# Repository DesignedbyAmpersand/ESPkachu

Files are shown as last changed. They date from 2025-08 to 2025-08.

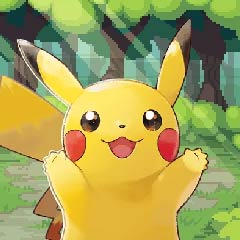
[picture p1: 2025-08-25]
wallpaper.jpg

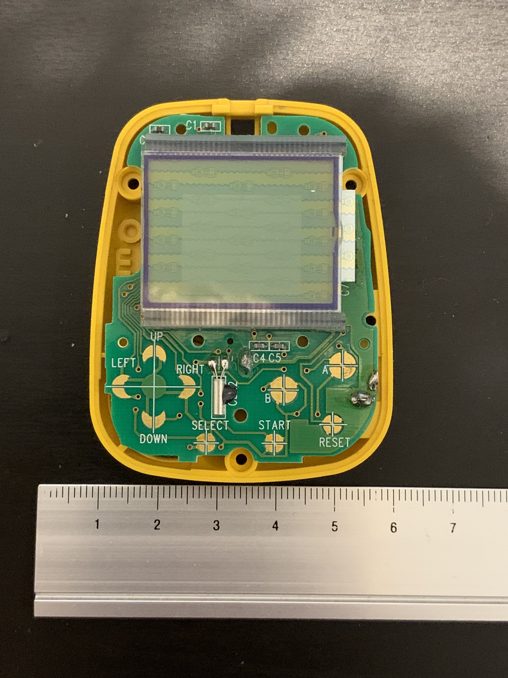
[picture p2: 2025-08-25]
IMG_2900.jpg

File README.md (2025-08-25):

https://www.reddit.com/r/SBCGaming/comments/13wpaec/this_is_espkachu

It’s an ESP32 inside a broken Pocket Pikachu. It uses Nathalis’s NCAT software to play NES, GBC, and SMS on a 1.3” IPS screen. There’s a 100mAh battery crammed in there that lasts 16 minutes, and it’s recharged via a tiny external PCB because I didn’t want to cut a massive hole for a USB C socket. The SD card can be accessed by unscrewing the battery cover. It uses all but 1 of the original screws with a bunch of the inside carved away to make space.

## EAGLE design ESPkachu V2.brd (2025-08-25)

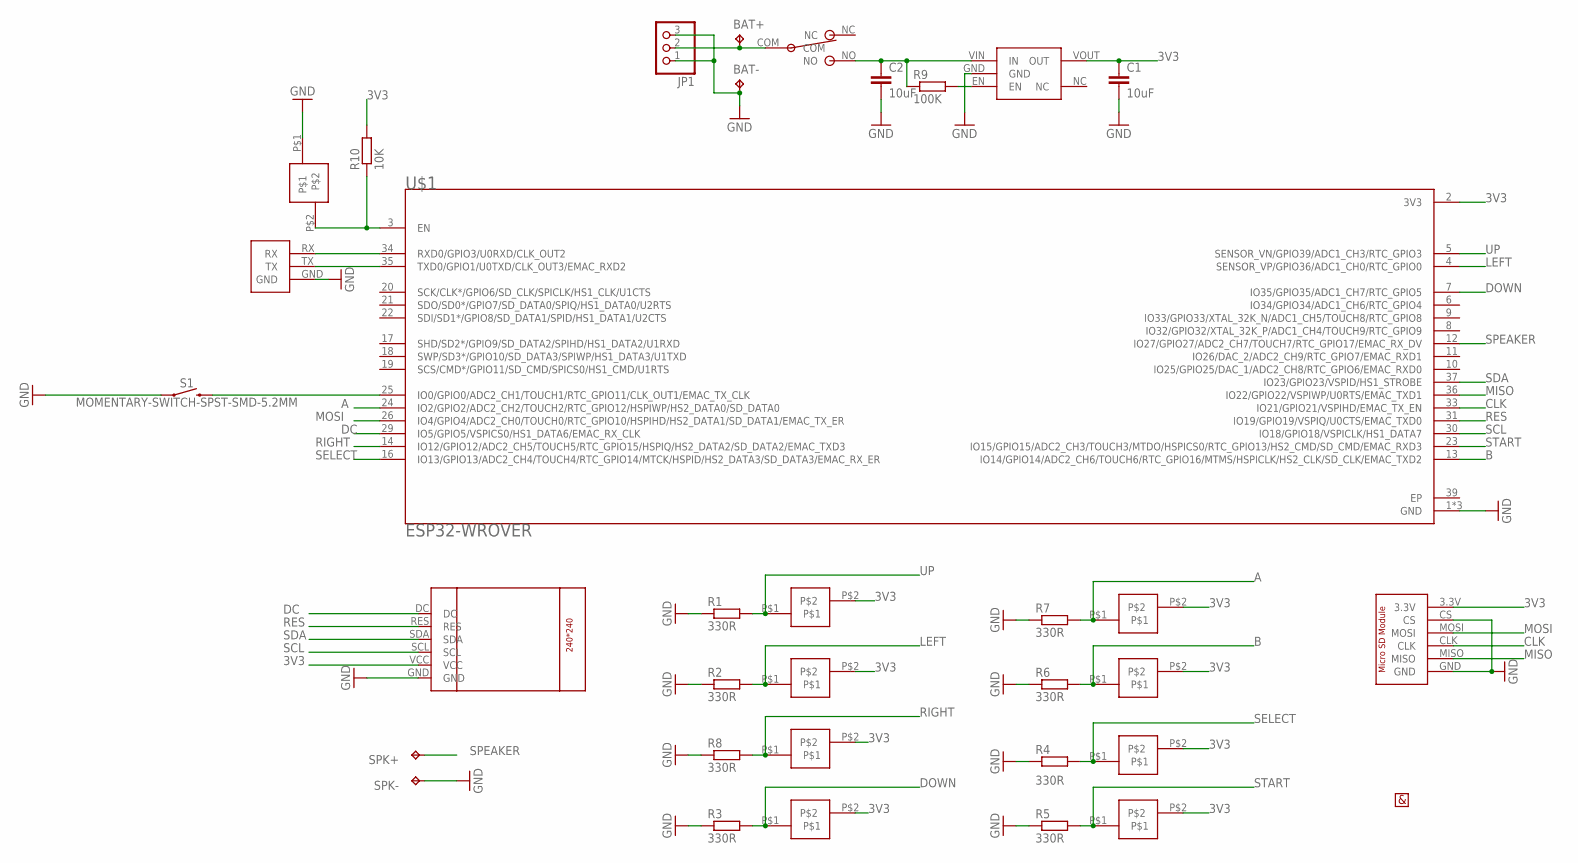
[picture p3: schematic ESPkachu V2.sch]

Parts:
A: ESPKACHU-PAD
B: ESPKACHU-PAD
BAT+: TPTP20R; TP20R
BAT-: TPTP20R; TP20R
C1, C2: 10uF; C0805
DOWN: ESPKACHU-PAD
JP1: PINHD-1X03_2.54-S; 1X03-S
LEFT: ESPKACHU-PAD
R1, R2, R3, R4, R5, R6, R7, R8: 330R; M0805
R9: 100K; M0805
R10: 10K; M0805
RESET: ESPKACHU-PAD
RIGHT: ESPKACHU-PAD
S1: MOMENTARY-SWITCH-SPST-SMD-5.2MM; TACTILE_SWITCH_SMD_5.2MM
SELECT: ESPKACHU-PAD
SPK+: TPTP20R; TP20R
SPK-: TPTP20R; TP20R
START: ESPKACHU-PAD
U$1: ESP32-WROVER; XCVR-ESP32-WROVER
U$2: LCD-ST7789-1.3INCH
U$3: ESPRESSO-MICROSD-MODULE
U$4: SS12D00-SWITCH
U$5: AMP-HALF
U$6: AP2112-REGULATOR; SOT25
U$7: ESPKACHU-UART
UP: ESPKACHU-PAD

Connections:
3V3: A.P$2, B.P$2, C1.1, DOWN.P$2, LEFT.P$2, R10.2, RIGHT.P$2, SELECT.P$2, START.P$2, U$1.2 (3V3), U$2.VCC, U$3.3.3V, U$6.VOUT (OUT), UP.P$2
A: A.P$1, R7.2, U$1.24 (IO2/GPIO2/ADC2_CH2/TOUCH2/RTC_GPIO12/HS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)
B: B.P$1, R6.2, U$1.13 (IO14/GPIO14/ADC2_CH6/TOUCH6/RTC_GPIO16/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)
CLK: U$1.33 (IO21/GPIO21/VSPIHD/EMAC_TX_EN), U$3.CLK
DC: U$1.29 (IO5/GPIO5/VSPICS0/HS1_DATA6/EMAC_RX_CLK), U$2.DC
DOWN: DOWN.P$1, R3.2, U$1.7 (IO35/GPIO35/ADC1_CH7/RTC_GPIO5)
EP: U$1.39 (EP)
GND: BAT-.TP, C1.2, C2.2, JP1.1, JP1.3, R1.1, R2.1, R3.1, R4.1, R5.1, R6.1, R7.1, R8.1, RESET.P$1, S1.1, S1.2 (1), SPK-.TP, U$1.1 (GND), U$1.15 (GND), U$1.38 (GND), U$2.GND, U$3.CS, U$3.GND, U$6.GND, U$7.GND
LEFT: LEFT.P$1, R2.2, U$1.4 (SENSOR_VP/GPIO36/ADC1_CH0/RTC_GPIO0)
MISO: U$1.36 (IO22/GPIO22/VSPIWP/U0RTS/EMAC_TXD1), U$3.MISO
MOSI: U$1.26 (IO4/GPIO4/ADC2_CH0/TOUCH0/RTC_GPIO10/HS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), U$3.MOSI
unnamed: R9.2, U$6.EN
unnamed: C2.1, R9.1, U$4.NO, U$6.VIN (IN)
unnamed: R10.1, RESET.P$2, U$1.3 (EN)
unnamed: S1.3 (2), S1.4 (2), U$1.25 (IO0/GPIO0/ADC2_CH1/TOUCH1/RTC_GPIO11/CL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)
unnamed: U$1.34 (RXD0/GPIO3/U0RXD/CLK_OUT2), U$7.RX
unnamed: U$1.35 (TXD0/GPIO1/U0TXD/CLK_OUT3/EMAC_RXD2), U$7.TX
unnamed: BAT+.TP, JP1.2, U$4.COM
RES: U$1.31 (IO19/GPIO19/VSPIQ/U0CTS/EMAC_TXD0), U$2.RES
RIGHT: R8.2, RIGHT.P$1, U$1.14 (IO12/GPIO12/ADC2_CH5/TOUCH5/RTC_GPIO15/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)
SCL: U$1.30 (IO18/GPIO18/VSPICLK/HS1_DATA7), U$2.SCL
SDA: U$1.37 (IO23/GPIO23/VSPID/HS1_STROBE), U$2.SDA
SELECT: R4.2, SELECT.P$1, U$1.16 (IO13/GPIO13/ADC2_CH4/TOUCH4/RTC_GPIO14/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)
SPEAKER: SPK+.TP, U$1.12 (IO27/GPIO27/ADC2_CH7/TOUCH7/RTC_GPIO17/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)
START: R5.2, START.P$1, U$1.23 (IO15/GPIO15/ADC2_CH3/TOUCH3/MTDO/HSPICS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)
UP: R1.2, U$1.5 (SENSOR_VN/GPIO39/ADC1_CH3/RTC_GPIO3), UP.P$1

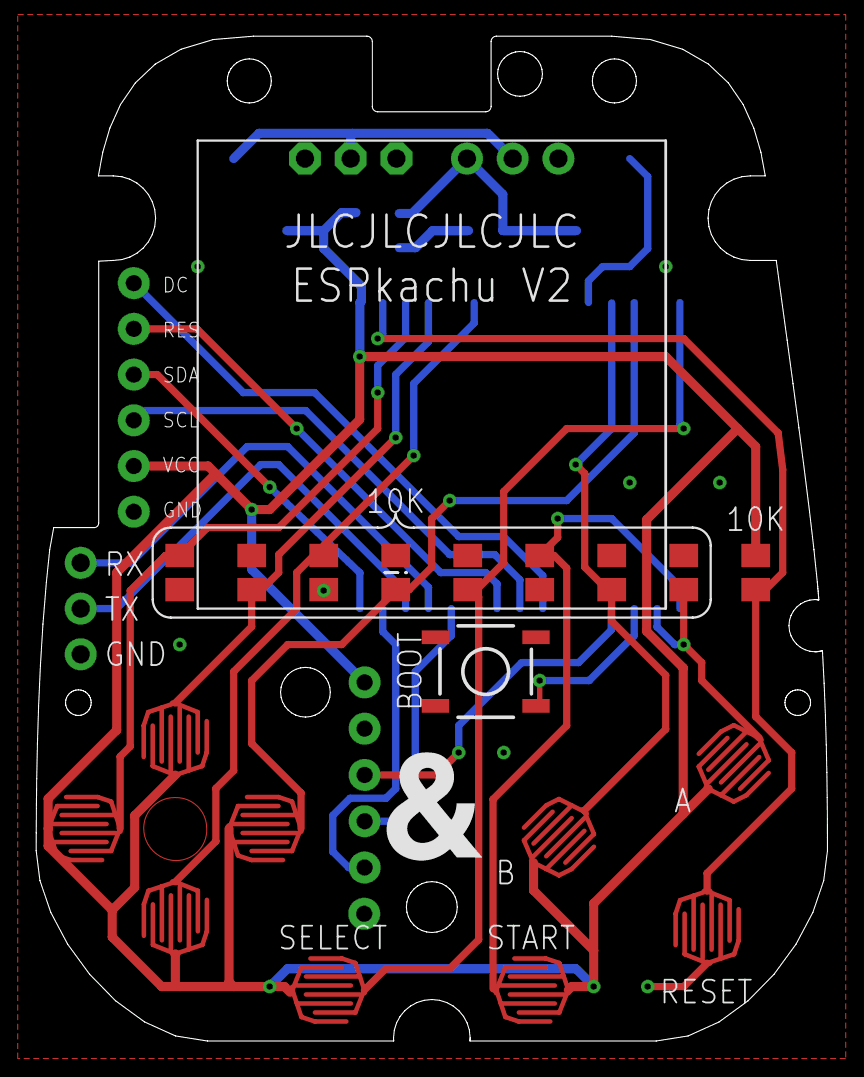
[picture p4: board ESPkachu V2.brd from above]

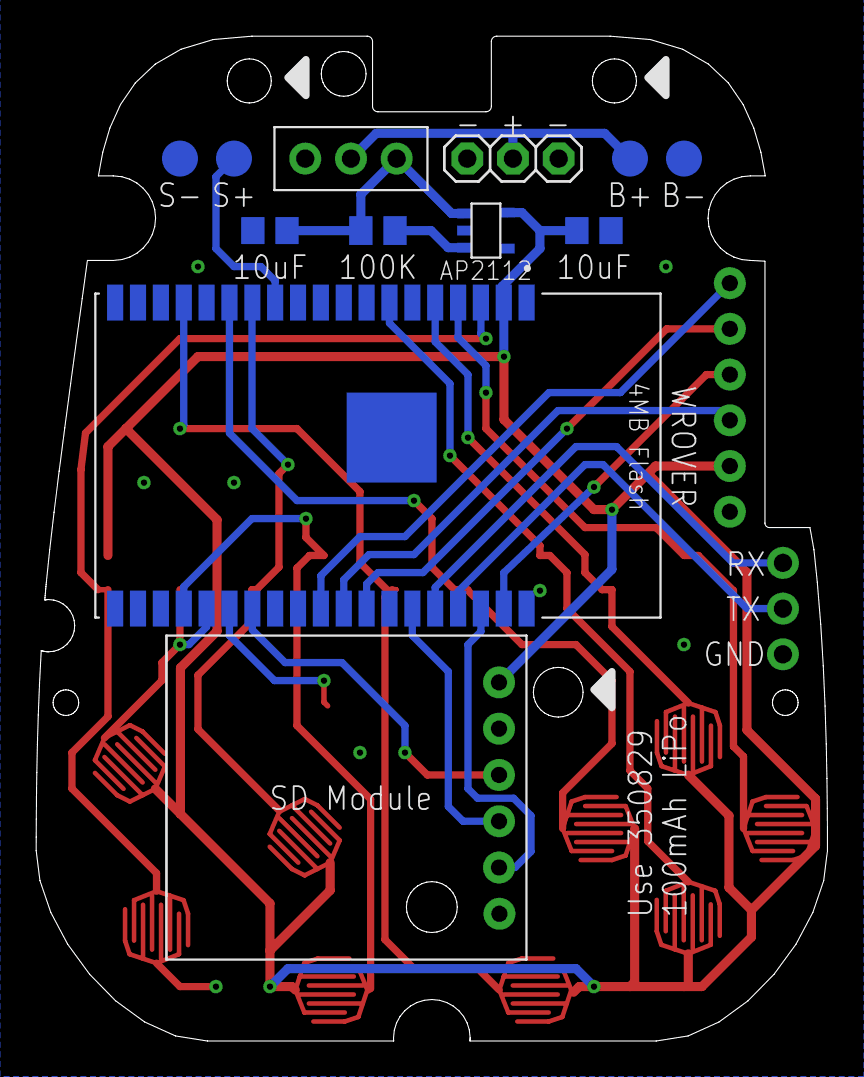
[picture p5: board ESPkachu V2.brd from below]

Board: 2 copper layers, 44.0 x 55.8 mm, 34 parts (13 on the bottom side), 25 nets.

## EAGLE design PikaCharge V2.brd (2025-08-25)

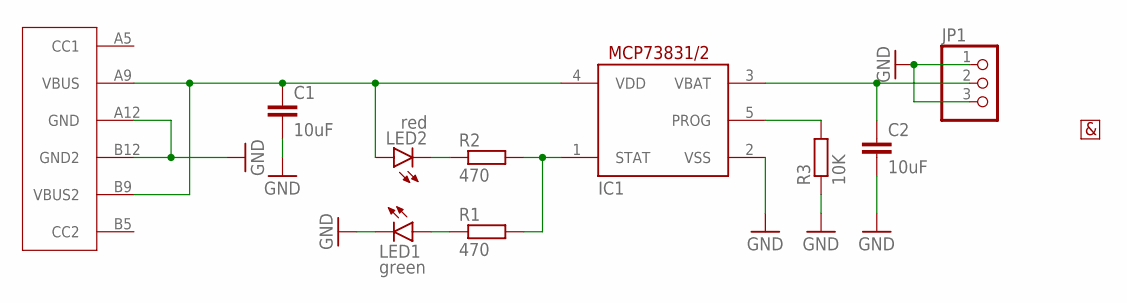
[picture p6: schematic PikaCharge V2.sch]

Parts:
C1, C2: 10uF; C0805
IC1: MCP73831/OT; SOT23-5L
JP1: PINHD-1X03_2.54-S; 1X03-S
LED1: green; CHIP-LED0805
LED2: red; CHIP-LED0805
R1, R2: 470; R0805
R3: 10K; R0805
U$1: USB-C-6PIN
U$2: AMP-HALF

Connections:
GND: C1.2, C2.2, IC1.2 (VSS), JP1.1, JP1.3, LED1.C, R3.1, U$1.A12 (GND), U$1.B12 (GND2)
unnamed: IC1.5 (PROG), R3.2
unnamed: IC1.1 (STAT), R1.2, R2.2
unnamed: LED2.C, R2.1
unnamed: LED1.A, R1.1
unnamed: C1.1, IC1.4 (VDD), LED2.A, U$1.A9 (VBUS), U$1.B9 (VBUS2)
unnamed: C2.1, IC1.3 (VBAT), JP1.2

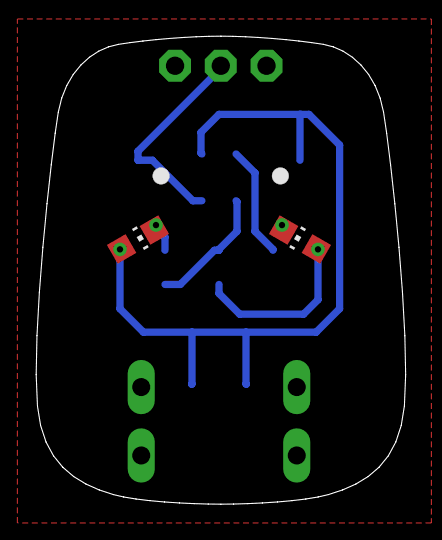
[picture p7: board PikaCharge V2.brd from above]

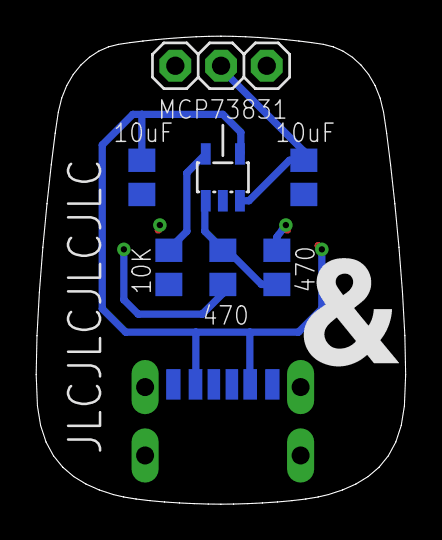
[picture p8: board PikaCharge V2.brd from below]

Board: 2 copper layers, 20.5 x 26.0 mm, 11 parts (9 on the bottom side), 7 nets.

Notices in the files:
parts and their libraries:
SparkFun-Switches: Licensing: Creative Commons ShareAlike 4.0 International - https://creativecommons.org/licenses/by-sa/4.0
